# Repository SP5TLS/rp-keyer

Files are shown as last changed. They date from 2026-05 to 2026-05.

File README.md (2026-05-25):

# rp-keyer

RP2040 / RP2350 firmware that turns a Raspberry Pi Pico (or Pico 2) into a
self-contained CW (Morse) keyer with:

* iambic / straight / bug / ultimatic / single-paddle keyer engine from
  [`radio-utils-keyer`](https://crates.io/crates/radio-utils-keyer),
* on-device CW decoder from
  [`radio-utils-cw-decoder`](https://crates.io/crates/radio-utils-cw-decoder)
  feeding the OLED decoded-text row,
* USB MIDI + USB CDC SERIAL_STATE paddle interface (same wire contract
  as [cw-adapter](https://github.com/sp5tls/cw-adapter)),
* PWM-driven passive piezo buzzer for sidetone,
* 2N2222 NPN driver to key a real radio,
* SSD1306 128×64 OLED + 4-button menu for keyer settings.

## Pinout (default for both Pico / Pico 2)

Pins are grouped into two physical clusters on the Pico header so wiring
stays tidy whether you fly leads or build a PCB.

**Left edge — keyer hardware:**

| Function | Pin | GPIO | Notes |
|---|-----|---|---|
| Buzzer / GND | 13  | GND  | Shared with radio-key return |
| Buzzer | 14  | GP10 | PWM5A, drives passive piezo |
| Radio key out | 15  | GP11 | Drives 2N2222 base via 1 kΩ resistor |
| Paddle GND | 18  | GND  | TRS sleeve |
| Dit paddle | 19  | GP14 | TRS tip, active-low, internal pull-up |
| Dah paddle | 20  | GP15 | TRS ring, active-low, internal pull-up |

**Right edge — OLED + 4-button combo module (single 8-wire connector):**

| Module pin | Pico pin | GPIO  | Function |
|---|---|---|---|
| K1 | 21 | GP16  | Button UP (top of stack) |
| K2 | 22 | GP17  | Button DOWN |
| GND | 23 | GND | Module ground |
| K3 | 24 | GP18  | Button OK |
| K4 | 25 | GP19  | Button BACK (bottom of stack) |
| SDA | 26 | GP20  | I2C0 SDA |
| SCL | 27 | GP21  | I2C0 SCL |
| VCC | 36 | 3V3 | Single jumper to 3V3 OUT |

All eight module wires land on the same edge of the Pico — seven on the
contiguous right-side strip (pins 21–27) plus one jumper to 3V3.

## Radio key wiring

```
   GP11 ─── 1 kΩ ──── Base
                       │
                    2N2222 NPN
                       │
                    ┌──┴──┐
                    │     │
               Collector  Emitter
                    │     │
   radio key tip ───┘     └─── GND ─── radio key sleeve
   (or PTT)
```

Connections:

* **Base** ← GP11 through the 1 kΩ current-limiting resistor.
* **Collector** ← radio key tip (or PTT line). The radio's keying
  supply provides the pull-up; the 2N2222 sinks this line to ground
  when GP11 is high.
* **Emitter** → GND, shared with the radio key sleeve so the
  firmware and the radio agree on ground reference.

Drop a flyback diode across the collector–emitter (cathode to
collector) if your radio's key line is inductive.

The schematic uses a **2N3904** in this position; a **2N2222** is a
drop-in substitute — both are general-purpose NPN signal transistors
with more than enough current capacity for keying a typical radio.

## Schematics

A KiCad 8 project for the reference carrier board lives under
[`schematics/rp-keyer/`](schematics/rp-keyer/). It contains:

* `rp-keyer1.kicad_pro` — project file (open this in KiCad)
* `rp-keyer1.kicad_sch` — schematic
* `rp-keyer1.kicad_pcb` — PCB layout

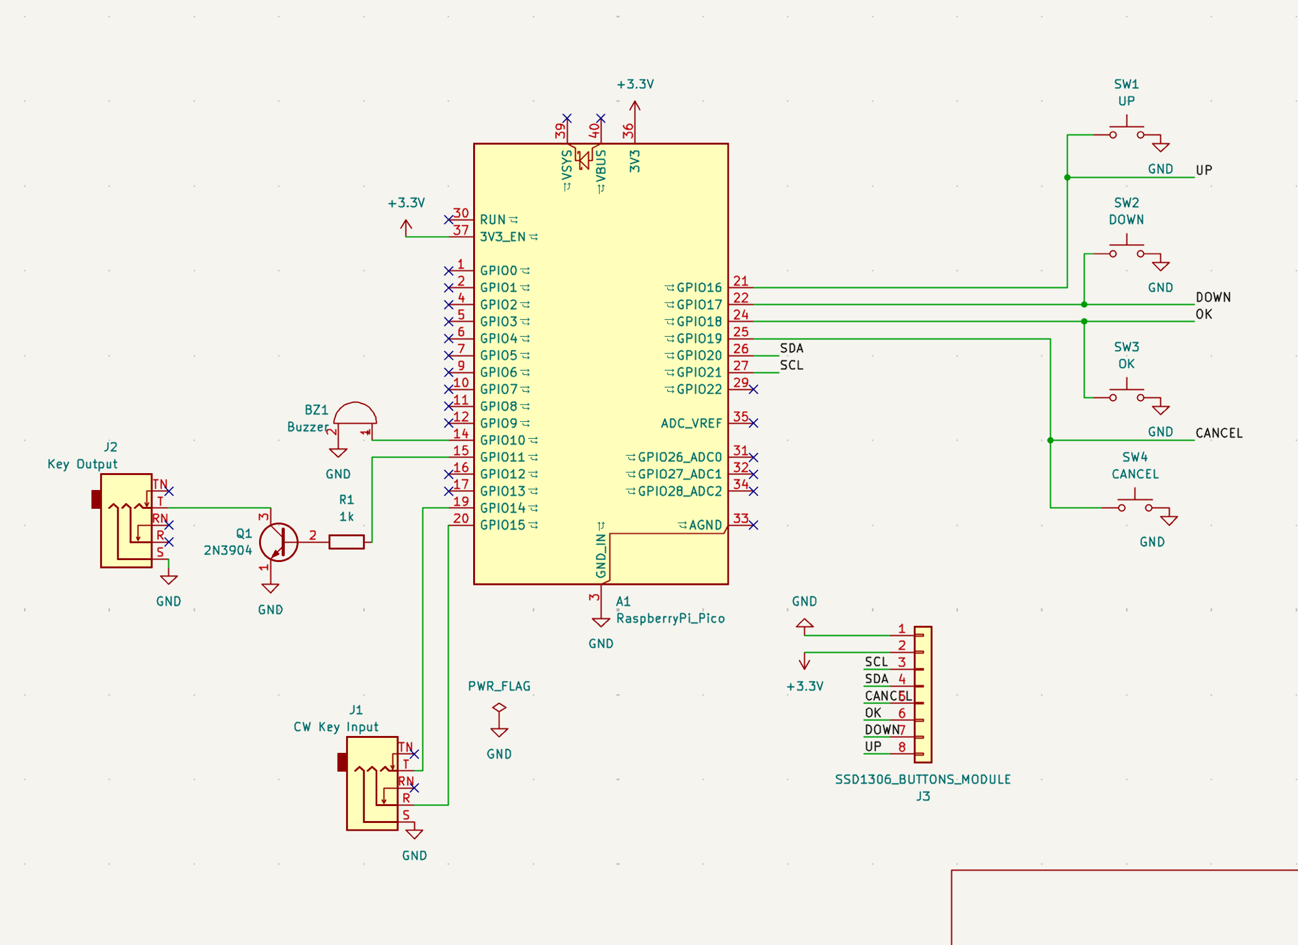
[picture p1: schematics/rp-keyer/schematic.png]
Schematic


The schematic captures the pinout above 1:1: paddle TRS jack `J1` on
GP14/GP15, radio-key TRS jack `J2` driven through Q1+R1 from GP11,
buzzer `BZ1` on GP10, and the 8-pin `SSD1306_BUTTONS_MODULE` connector
`J3` carrying SDA/SCL plus K1..K4 to GP16..GP21 with 3V3 + GND from the
top of the Pico.

## Pre-built firmware

Each tagged release publishes ready-to-flash `.uf2` files for both
boards on the [GitHub Releases page](https://github.com/sp5tls/rp-keyer/releases).
Hold BOOTSEL while plugging the board in, then drag the `.uf2` onto the
USB drive that appears.

## Building from source

```sh
# RP2040 (Pico)
cargo build --release \
  --target thumbv6m-none-eabi \
  --features rp2040,serial,midi \
  --bin rp2040

# RP2350 (Pico 2)
cargo build --release \
  --target thumbv8m.main-none-eabihf \
  --features rp2350,serial,midi \
  --bin rp2350
```

Generate a `.uf2` from the ELF:

```sh
cargo install elf2uf2-rs

elf2uf2-rs target/thumbv6m-none-eabi/release/rp2040 rp-keyer-rp2040.uf2
# For RP2350: elf2uf2-rs hardcodes the RP2040 family ID, so rewrite it
# afterwards or the Pico 2 BOOTSEL drive will reject the file.
elf2uf2-rs target/thumbv8m.main-none-eabihf/release/rp2350 rp-keyer-rp2350.uf2
python3 scripts/patch_uf2_family.py rp-keyer-rp2350.uf2
```

Flashing via `probe-rs`:

```sh
cargo run --release \
  --target thumbv6m-none-eabi \
  --features rp2040,serial,midi \
  --bin rp2040
```

## Menu

Boot screen shows the live mode / WPM / sidetone frequency.  `OK` enters
the settings list; `UP`/`DOWN` scroll, `OK` enters an item for editing,
`UP`/`DOWN` change the value, `OK` / `BACK` return.

Settable parameters:

* Mode (Straight / IambicA / IambicB / Bug / Ultimatic / SinglePaddle)
* WPM (5 – 60)
* Weight (25 – 75)
* Sidetone frequency (300 – 1200 Hz)
* Sidetone volume (0 – 100 %)
* Hang time (0 – 2000 ms)
* Keys reversed (Y / N)
* Iambic-B CMOS timing percentage (0 – 100)
* Farnsworth WPM (0 – 60, 0 = off)
* Keying compensation (0 – 50 ms)

## License

Dual-licensed under either of:

- [MIT license](LICENSE-MIT)
- [Apache License, Version 2.0](LICENSE-APACHE)

at your option.

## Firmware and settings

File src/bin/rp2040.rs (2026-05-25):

#![no_std]
#![no_main]

extern crate alloc;

#[cfg(feature = "serial")]
use rp_keyer::cdc_serial_state::{CdcWithSerialState, State as CdcState};
#[cfg(feature = "midi")]
use rp_keyer::midi_interrupt::MidiInterruptClass;

use rp_keyer::buttons::{ButtonInput, ButtonPanel};
use rp_keyer::buzzer::Buzzer;
use rp_keyer::radio_key::RadioKey;
use rp_keyer::shared::{ConfigDirtySignal, SharedConfig, SharedDecoder, UsbStateSignal};
use rp_keyer::storage::{self, AsyncFlash, FLASH_TOTAL_SIZE};
use rp_keyer::ui::{OledI2c, Ui};
use rp_keyer::usb_emit_task::UsbEmitApp;

use defmt::*;
use embassy_executor::{InterruptExecutor, Spawner};
use embassy_futures::select::{Either, select};
use embassy_rp::bind_interrupts;
use embassy_rp::flash::{Blocking, Flash};
use embassy_rp::gpio::{Input, Level, Output, Pull};
use embassy_rp::i2c::{self, Config as I2cConfig, I2c};
use embassy_rp::peripherals::{FLASH, I2C0, USB};
use embassy_rp::pwm::{Config as PwmConfig, Pwm};
use embassy_rp::usb::{Driver, InterruptHandler};
use embassy_time::{Duration, Timer};
use embassy_usb::Builder;
use embedded_alloc::LlffHeap as Heap;
use radio_utils_keyer::KeyerConfig;
use static_cell::StaticCell;

use {defmt_rtt as _, panic_probe as _};

defmt::timestamp!("{=u64:us}", embassy_time::Instant::now().as_micros());

#[defmt::panic_handler]
fn panic() -> ! {
    rp_keyer::safe_stop();
    cortex_m::asm::udf()
}

// ── Global allocator ─────────────────────────────────────────────────────
// The keyer engine uses Vec/VecDeque internally for text macros and the
// text_queue.  64 KiB is comfortable: macros peak at a few hundred
// elements; the transition log is a fixed-size heapless ring (see
// `MAX_RECORDED_TRANSITIONS` in radio_utils_keyer::engine) so it doesn't
// touch the heap at all; menu strings are heapless::String.
#[global_allocator]
static HEAP: Heap = Heap::empty();
const HEAP_SIZE: usize = 65_536;
static mut HEAP_MEM: [u8; HEAP_SIZE] = [0; HEAP_SIZE];

bind_interrupts!(struct Irqs {
    USBCTRL_IRQ => InterruptHandler<USB>;
    I2C0_IRQ => i2c::InterruptHandler<I2C0>;
});

// ── Shared state ─────────────────────────────────────────────────────────
static SHARED_CONFIG: StaticCell<SharedConfig> = StaticCell::new();
static KEY_INDICATOR: portable_atomic::AtomicBool = portable_atomic::AtomicBool::new(false);
/// `true` whenever the keyer engine is mid-element / has a held paddle
/// or pending PTT hang; updated each engine tick.  The persistence
/// task waits for this to fall to `false` before committing a save so
/// the ~50 ms flash-erase pause doesn't interrupt active keying.
static ENGINE_ACTIVE: portable_atomic::AtomicBool = portable_atomic::AtomicBool::new(false);
/// Handshake: the persistence task sets this to `true` after observing
/// `ENGINE_ACTIVE == false` and before calling the (~50 ms,
/// IRQs-disabled) flash erase.  The keyer task checks it at the top
/// of every iteration and parks if set — closes the race where the
/// engine could start keying between the persistence task's load and
/// the erase entry.  See `keyer_task::run`'s prologue and the
/// `config_persist_task` handshake comment.
static SAVE_LOCK: portable_atomic::AtomicBool = portable_atomic::AtomicBool::new(false);
/// Keyer → USB emit task channel.  Lossy by design — only the latest
/// snapshot matters; the consumer caches `prev_*` so a write failure
/// can't drop an edge.
static USB_SIGNAL: UsbStateSignal = embassy_sync::signal::Signal::new();
/// UI → persistence task — set on every config-mutating button press.
/// The persistence task debounces and waits for engine idle before
/// committing.
static CONFIG_DIRTY: ConfigDirtySignal = embassy_sync::signal::Signal::new();
/// Backing storage for the per-device USB serial number derived from
/// the flash unique-ID; lives in `.bss` so the descriptor table can
/// borrow it `'static`.
static SERIAL_BUF: StaticCell<[u8; 16]> = StaticCell::new();
/// CW decoder, shared between the keyer task (transition feeder) and
/// the UI task (poll + snapshot for the main-screen text row).  See
/// `shared::SharedDecoder` for the locking model.
static DECODER: SharedDecoder = embassy_sync::blocking_mutex::Mutex::new(core::cell::RefCell::new(
    radio_utils_cw_decoder::Decoder::new(),
));

// ── Tasks ────────────────────────────────────────────────────────────────
#[embassy_executor::task]
async fn usb_task(mut usb: embassy_usb::UsbDevice<'static, Driver<'static, USB>>) {
    usb.run().await;
}

#[embassy_executor::task]
async fn keyer_task(
    dit_pin: Input<'static>,
    dah_pin: Input<'static>,
    radio_key: RadioKey,
    buzzer: Buzzer,
    shared_config: &'static SharedConfig,
) {
    rp_keyer::keyer_task::run(
        dit_pin,
        dah_pin,
        radio_key,
        buzzer,
        shared_config,
        &KEY_INDICATOR,
        &USB_SIGNAL,
        &ENGINE_ACTIVE,
        &SAVE_LOCK,
        &DECODER,
    )
    .await;
}

#[embassy_executor::task]
async fn usb_emit_task(mut app: UsbEmitApp<'static, Driver<'static, USB>>) {
    app.run(&USB_SIGNAL).await;
}

#[embassy_executor::task]
async fn ui_task(
    i2c: OledI2c,
    mut buttons: ButtonPanel,
    shared_config: &'static SharedConfig,
) -> ! {
    let mut ui = Ui::new(i2c).await;

    let mut btn_buf = [rp_keyer::buttons::ButtonEvent::Up; 4];
    // Cached WPM + enabled flag for the decoder poll. Both refreshed
    // every render below; seeded from the persisted config so the very
    // first poll uses the right threshold and (when disabled) skips
    // the lock entirely.
    let (mut decoder_wpm, mut decoder_enabled) = {
        let cfg = shared_config.lock().await;
        (cfg.speed_wpm, cfg.decoder_enabled)
    };
    let mut decoded_buf = [0u8; 32];
    loop {
        ui.note_key_state(KEY_INDICATOR.load(portable_atomic::Ordering::Relaxed));

        let events = buttons.poll(&mut btn_buf);
        if !events.is_empty() {
            let mut guard = shared_config.lock().await;
            for &ev in events {
                ui.on_button(ev, &mut guard);
            }
            // Drop the guard before render so we don't hold it during
            // the (blocking) I2C flush.
            drop(guard);
            // Signal the persistence task on any edit — it debounces +
            // waits for idle before actually writing flash.
            if ui.take_config_changed() {
                CONFIG_DIRTY.signal(());
            }
        }

        // Poll + snapshot the decoder when it's enabled.  Closure runs
        // under a critical section — keep it strictly to the decoder
        // calls and a small memcpy.  Both keyer task (writer) and UI
        // task (reader) take this lock; lock duration ≪ 1 µs so the
        // keyer task on SWI_IRQ_1 is never delayed appreciably.
        if decoder_enabled {
            let now_us = embassy_time::Instant::now().as_micros();
            let n = DECODER.lock(|d| {
                let mut d = d.borrow_mut();
                d.poll(now_us, decoder_wpm);
                d.snapshot(&mut decoded_buf)
            });
            ui.note_decoded(&decoded_buf[..n]);
        }

        // Only snapshot the config when there's actually something to
        // draw — avoids the [String; 8] clone + critical section every
        // 25 ms when nothing on screen changed.
        if ui.is_dirty() {
            let cfg_snap: KeyerConfig = shared_config.lock().await.clone();
            decoder_wpm = cfg_snap.speed_wpm;
            decoder_enabled = cfg_snap.decoder_enabled;
            ui.render(&cfg_snap);
        }

        Timer::after(Duration::from_millis(25)).await;
    }
}

/// Debounce-and-commit task for settings persistence.
///
/// State machine: wait → debounce → acquire-save-window → save.
///
/// * **wait** — block on `CONFIG_DIRTY` until the UI signals an edit.
/// * **debounce** — each further edit within 3 s extends the window.
///   Avoids 8 flash writes when the user scrolls a slider up by 8.
/// * **acquire-save-window** — flash erase disables interrupts for
///   ~50 ms, so we need the keyer engine to be quiescent for the
///   duration.  Two-step handshake:
///
///     1. wait for `ENGINE_ACTIVE == false`,
///     2. set `SAVE_LOCK = true` and wait one millisecond (4 keyer
///        ticks at the 250 µs cadence) for the keyer to observe it,
///     3. recheck `ENGINE_ACTIVE`.  If it raced (paddle press landed
///        in step 1's gap before the keyer parked), release the lock
///        and retry.  Otherwise the keyer is parked at its prologue
///        and won't drive the key line until we clear `SAVE_LOCK`.
///
/// * **save** — snapshot the shared config and append to the ring.
///   IRQs go off for ~50 ms during the erase; the keyer task is
///   already parked, so this is safe.  Clear `SAVE_LOCK` when done.
#[embassy_executor::task]
async fn config_persist_task(mut flash: AsyncFlash, shared_config: &'static SharedConfig) {
    const DEBOUNCE: Duration = Duration::from_secs(3);
    const IDLE_RECHECK: Duration = Duration::from_millis(250);
    /// Long enough for the keyer task (250 µs cadence) to observe
    /// SAVE_LOCK and have updated ENGINE_ACTIVE one more time so the
    /// recheck reflects post-park reality.
    const PARK_OBSERVE: Duration = Duration::from_millis(1);

    loop {
        // Wait for the first dirty signal of this batch.
        CONFIG_DIRTY.wait().await;

        // Debounce: each new dirty signal restarts the 3-second window.
        // The loop exits as soon as `Timer::after(DEBOUNCE)` wins, i.e.
        // the user has been quiet for the full window.
        while let Either::First(_) = select(CONFIG_DIRTY.wait(), Timer::after(DEBOUNCE)).await {}

        // Acquire-save-window handshake — see task docstring.
        loop {
            while ENGINE_ACTIVE.load(portable_atomic::Ordering::Relaxed) {
                Timer::after(IDLE_RECHECK).await;
            }
            SAVE_LOCK.store(true, portable_atomic::Ordering::Relaxed);
            Timer::after(PARK_OBSERVE).await;
            if !ENGINE_ACTIVE.load(portable_atomic::Ordering::Relaxed) {
                break;
            }
            // Raced — a paddle press landed between the engine-active
            // check and the lock store.  Release and retry.
            SAVE_LOCK.store(false, portable_atomic::Ordering::Relaxed);
            Timer::after(IDLE_RECHECK).await;
        }

        let cfg = shared_config.lock().await.clone();
        match storage::save_config(&mut flash, &cfg).await {
            Ok(()) => info!("settings saved"),
            Err(()) => warn!("settings save failed"),
        }
        SAVE_LOCK.store(false, portable_atomic::Ordering::Relaxed);
    }
}

// ── Interrupt executor for the keyer task ────────────────────────────────
static EXECUTOR_HIGH: InterruptExecutor = InterruptExecutor::new();

#[unsafe(no_mangle)]
#[allow(non_snake_case)]
unsafe extern "C" fn SWI_IRQ_1() {
    unsafe { EXECUTOR_HIGH.on_interrupt() }
}

/// Read the RP2040 flash unique ID and format it as 16 hex chars into
/// `buf`.  Falls back to a fixed string if the flash read errors so
/// the USB enumeration still has *some* serial.
fn read_flash_serial_into(
    flash: &mut Flash<'static, FLASH, Blocking, { FLASH_TOTAL_SIZE }>,
    buf: &'static mut [u8; 16],
) -> &'static str {
    let mut uid = [0u8; 8];
    if flash.blocking_unique_id(&mut uid).is_ok() {
        const HEX: &[u8; 16] = b"0123456789abcdef";
        for (i, byte) in uid.iter().enumerate() {
            buf[2 * i] = HEX[(byte >> 4) as usize];
            buf[2 * i + 1] = HEX[(byte & 0x0F) as usize];
        }
    } else {
        // Deterministic 16-byte fallback so two enumeration attempts
        // don't churn the OS's USB device cache.
        buf.copy_from_slice(b"rpk-rp2040-0000\0");
    }
    // Safety: every byte above is ASCII (hex digits or the printable
    // fallback string), so it's valid UTF-8.
    unsafe { core::str::from_utf8_unchecked(buf.as_slice()) }
}

// ── Main ─────────────────────────────────────────────────────────────────
#[embassy_executor::main]
async fn main(spawner: Spawner) {
    // Initialise the heap before anything that touches the keyer crate
    // (KeyerEngine::new allocates a Vec).
    unsafe {
        HEAP.init(core::ptr::addr_of_mut!(HEAP_MEM) as usize, HEAP_SIZE);
    }

    let p = embassy_rp::init(Default::default());

    info!("radio-utils-firmware booting (RP2040)");

    // ── Flash driver: unique-ID read for USB serial + settings ring ──
    let mut flash: Flash<'static, FLASH, Blocking, { FLASH_TOTAL_SIZE }> =
        Flash::new_blocking(p.FLASH);
    let serial_number = read_flash_serial_into(&mut flash, SERIAL_BUF.init([0u8; 16]));
    let mut async_flash = AsyncFlash::new(flash);

    // ── Try to load saved settings; fall back to defaults ────────────
    let initial_cfg: KeyerConfig = match storage::load_config(&mut async_flash).await {
        Some(cfg) => {
            info!("settings restored from flash");
            cfg
        }
        None => {
            info!("no saved settings — using defaults");
            KeyerConfig::default()
        }
    };

    // ── Shared keyer config ──────────────────────────────────────────
    let shared_config: &'static SharedConfig =
        SHARED_CONFIG.init(embassy_sync::mutex::Mutex::new(initial_cfg));

    // ── USB ──────────────────────────────────────────────────────────
    let driver = Driver::new(p.USB, Irqs);
    let mut usb_config = embassy_usb::Config::new(0x16c0, 0x27dc);
    usb_config.manufacturer = Some("radio-utils");
    usb_config.product = Some("CW Keyer + Interface");
    usb_config.serial_number = Some(serial_number);
    usb_config.max_power = 100;
    usb_config.max_packet_size_0 = 64;

    static CONFIG_DESCRIPTOR: StaticCell<[u8; 512]> = StaticCell::new();
    static BOS_DESCRIPTOR: StaticCell<[u8; 256]> = StaticCell::new();
    static CONTROL_BUF: StaticCell<[u8; 64]> = StaticCell::new();

    let mut builder = Builder::new(
        driver,
        usb_config,
        CONFIG_DESCRIPTOR.init([0; 512]),
        BOS_DESCRIPTOR.init([0; 256]),
        &mut [],
        CONTROL_BUF.init([0; 64]),
    );

    #[cfg(feature = "serial")]
    let serial = {
        static CDC_STATE: StaticCell<CdcState> = StaticCell::new();
        Some(CdcWithSerialState::new(
            &mut builder,
            CDC_STATE.init(CdcState::new()),
            64,
        ))
    };

    #[cfg(feature = "midi")]
    let midi = Some(MidiInterruptClass::new(&mut builder, 1, 0, 64, 1));

    let usb = builder.build();
    spawner.spawn(usb_task(usb).unwrap());

    // Pinout is grouped into two physical clusters on the Pico header so
    // both flying-lead wiring and a future PCB stay tidy. See README.
    //
    // Left edge — keyer hardware:
    //   pin 14 GP10 buzzer (PWM5A)
    //   pin 15 GP11 radio key out (2N2222 base)
    //   pin 19 GP14 Dit paddle  (TRS tip,   GND on pin 18)
    //   pin 20 GP15 Dah paddle  (TRS ring,  GND on pin 18)
    //
    // Right edge — OLED + 4-button combo module (8-wire connector):
    //   pin 21 GP16 K1 = UP
    //   pin 22 GP17 K2 = DOWN
    //   pin 23 GND  module GND
    //   pin 24 GP18 K3 = OK
    //   pin 25 GP19 K4 = BACK
    //   pin 26 GP20 SDA (I2C0)
    //   pin 27 GP21 SCL (I2C0)
    //   pin 36 3V3  module VCC

    let dit_pin = Input::new(p.PIN_14, Pull::Up);
    let dah_pin = Input::new(p.PIN_15, Pull::Up);

    let radio_key = RadioKey::new(Output::new(p.PIN_11, Level::Low));

    let buzzer = {
        let pwm_cfg = PwmConfig::default();
        let pwm = Pwm::new_output_a(p.PWM_SLICE5, p.PIN_10, pwm_cfg);
        Buzzer::new(pwm)
    };

    let oled_i2c: OledI2c = {
        let mut cfg = I2cConfig::default();
        cfg.frequency = 400_000;
        I2c::new_blocking(p.I2C0, p.PIN_21, p.PIN_20, cfg)
    };

    let buttons = ButtonPanel {
        up: ButtonInput::new(Input::new(p.PIN_16, Pull::Up)),
        down: ButtonInput::new(Input::new(p.PIN_17, Pull::Up)),
        ok: ButtonInput::new(Input::new(p.PIN_18, Pull::Up)),
        back: ButtonInput::new(Input::new(p.PIN_19, Pull::Up)),
    };

    // ── Spawn UI + USB emit + persistence on the thread executor ─────
    spawner.spawn(ui_task(oled_i2c, buttons, shared_config).unwrap());
    spawner.spawn(config_persist_task(async_flash, shared_config).unwrap());

    let usb_emit_app = UsbEmitApp {
        #[cfg(feature = "serial")]
        serial,
        #[cfg(feature = "midi")]
        midi,
        #[cfg(not(any(feature = "serial", feature = "midi")))]
        _marker: core::marker::PhantomData,
    };
    spawner.spawn(usb_emit_task(usb_emit_app).unwrap());

    // ── Interrupt priorities ─────────────────────────────────────────
    // All NVIC priorities default to P0; the InterruptExecutor running
    // on SWI_IRQ_1 then can't preempt USBCTRL_IRQ / I2C0_IRQ even
    // though it's the highest-latency-sensitive code on the chip.
    // Lower USB + I2C to P3 (lowest) and keep SWI at P0 so the keyer
    // task can actually meet its 250 µs cadence.
    use embassy_rp::interrupt::{InterruptExt, Priority};
    embassy_rp::interrupt::USBCTRL_IRQ.set_priority(Priority::P3);
    embassy_rp::interrupt::I2C0_IRQ.set_priority(Priority::P3);
    embassy_rp::interrupt::SWI_IRQ_1.set_priority(Priority::P0);

    // ── Spawn keyer task on the elevated-priority interrupt executor ─
    let hi_spawner = EXECUTOR_HIGH.start(embassy_rp::pac::Interrupt::SWI_IRQ_1);

    hi_spawner.spawn(keyer_task(dit_pin, dah_pin, radio_key, buzzer, shared_config).unwrap());

    loop {
        embassy_time::Timer::after(embassy_time::Duration::from_secs(3600)).await;
    }
}

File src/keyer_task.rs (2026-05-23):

//! High-priority keyer loop.
//!
//! Runs on the interrupt executor at a 250 µs cadence.  Paddle reads,
//! debouncing, USB-snapshot signalling and engine ticks all happen
//! every 250 µs — the engine is constructed via `new_with_tick(_, 250)`
//! so each `tick()` advances `elapsed_us` by 250 µs and the
//! schedule-phase residual handling is matched to the same quantum.
//!
//! At the previous 1 ms engine quantum, 28 WPM produced a repeating
//! 43-43-43-43-43-43-42 ms dit pattern because `1200 / 28 = 42.857 ms`
//! doesn't fall on a 1 ms grid; the residual built up and the engine
//! emitted a short dit every 7 elements.  At 250 µs that swing shrinks
//! to a single tick (250 µs) — below the audibility threshold and
//! within the bound the schedule-phase carry was designed for.
//!
//! USB I/O does **not** run in this task.  A `Signal<UsbSnapshot>`
//! carries the latest paddle / engine-key state to a separate
//! low-priority `usb_emit_task`, so a USB endpoint poll (≤ 1 ms per
//! interrupt-IN transfer) can never stretch the keyer's 250 µs cadence
//! and warp the engine's perception of wall-clock time.
//!
//! Paddle debounce: `debounce_threshold × 250 µs` — currently ~2 ms
//! (8 samples) to stay above real-world paddle contact bounce.  Tighter
//! thresholds let release-bounce sneak through and the iambic memory
//! turns one tap into two elements (see `dit_debounce` in `run`).

use embassy_rp::gpio::Input;
use embassy_time::{Duration, Instant, Ticker};
use radio_utils_keyer::{KeyerConfig, KeyerEngine, KeyerOutput, UsbEmitStyle};

use crate::buzzer::Buzzer;
use crate::paddle::Debouncer;
use crate::radio_key::RadioKey;
use crate::shared::{SharedConfig, SharedDecoder, UsbSnapshot, UsbStateSignal};

/// Keyer poll + engine tick interval.  Drives both the paddle debounce
/// cadence and the engine's time advance — both updated at this rate.
const POLL_INTERVAL_US: u32 = 250;

/// Config refresh throttle, expressed in ticks.  ~50 ms between
/// re-locks of the shared mutex (200 × 250 µs).
const CONFIG_REFRESH_TICKS: u32 = (50 * 1000) / POLL_INTERVAL_US;

/// Feed a key transition to the CW decoder. Held under the decoder's
/// critical-section lock for just the duration of `on_transition` —
/// O(1) work, well under a microsecond, so it never extends the
/// keyer task's 250 µs cadence.
///
/// Called twice in close succession for each key-down: once from
/// `PttRequest(true)` (one engine tick before the actual element
/// edge) and once from the following `KeyDown`. That matches the
/// on-air key line — `PttRequest(true)` already drives the GPIO low —
/// so the decoder is correctly observing the keyed signal. The second
/// call lands with `state == Down`, so `process_gap` short-circuits;
/// only `last_transition_us` advances by the ~250 µs between the two
/// events, which biases the next gap by the same amount (≈ 0.4% of a
/// dit at 18 WPM — well below decode-threshold sensitivity).
#[inline]
fn feed_decoder(decoder: &'static SharedDecoder, key_down: bool, wpm: u8) {
    let now_us = Instant::now().as_micros();
    decoder.lock(|d| d.borrow_mut().on_transition(now_us, key_down, wpm));
}

/// Main keyer loop.  Never returns.
#[allow(clippy::too_many_arguments)] // each parameter is a distinct piece of wiring with no natural grouping
pub async fn run(
    dit_pin: Input<'static>,
    dah_pin: Input<'static>,
    mut radio_key: RadioKey,
    mut buzzer: Buzzer,
    shared_config: &'static SharedConfig,
    key_indicator: &'static portable_atomic::AtomicBool,
    usb_signal: &'static UsbStateSignal,
    engine_active: &'static portable_atomic::AtomicBool,
    save_lock: &'static portable_atomic::AtomicBool,
    decoder: &'static SharedDecoder,
) -> ! {
    // Seed the engine with the current config snapshot.
    let mut keys_reversed: bool;
    let mut emit_style: UsbEmitStyle;
    let mut wpm: u8;
    let mut decoder_enabled: bool;
    let initial_cfg: KeyerConfig = {
        let guard = shared_config.lock().await;
        keys_reversed = guard.keys_reversed;
        emit_style = guard.usb_emit_style;
        wpm = guard.speed_wpm;
        decoder_enabled = guard.decoder_enabled;
        guard.clone()
    };
    buzzer.update_settings(initial_cfg.sidetone_freq, initial_cfg.sidetone_volume);
    let mut engine = KeyerEngine::new_with_tick(initial_cfg, POLL_INTERVAL_US);

    // 8 consecutive samples ≈ 2 ms debounce.  Mechanical paddles
    // can bounce for 1–3 ms on release; anything shorter lets the
    // bounce-back-to-pressed rising edge through and the iambic
    // engine latches it as a fresh dit_memory during the next
    // inter-element gap, producing a phantom second dit (the
    // classic "double-dit on one tap" failure mode at 18 WPM).
    // 2 ms is far below the shortest intentional dit at 60 WPM
    // (≈ 20 ms) so it costs nothing in element fidelity.
    let mut dit_debounce = Debouncer::new(false, 8);
    let mut dah_debounce = Debouncer::new(false, 8);

    // Live engine key state — flipped by KeyDown/KeyUp/PttRequest(true)
    // and shipped to usb_emit_task via the Signal so the host sees
    // engine-keyed transitions even in Keyed emit mode.
    let mut live_key: bool = false;
    let mut last_signaled: Option<UsbSnapshot> = None;

    // Counts engine ticks for the config-refresh throttle.  Resets to
    // 0 on each fire rather than wrapping a u32 — avoids a spurious
    // refresh at u32::MAX → 0 (the previous `is_multiple_of` check
    // matched 0 too, so the wrap moment triggered an extra refresh).
    let mut refresh_counter: u32 = 0;

    // Fixed-interval ticker rather than `Timer::after(POLL_INTERVAL_US)`
    // — the latter measures from end-of-body, so any per-iteration jitter
    // (engine state branch, periodic config clone, etc.) accumulated as
    // wall-clock drift while the engine's `elapsed_us` advanced by a
    // fixed quantum per tick.  `Ticker` fires on absolute interval
    // boundaries so engine ticks track wall clock.
    let mut ticker = Ticker::every(Duration::from_micros(POLL_INTERVAL_US as u64));
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

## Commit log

2026-05-23 Initial commit: rp-keyer firmware for RP2040 / RP2350
    Stand-alone firmware crate extracted from the radio-utils workspace
    (was crates/radio-utils-firmware there) so it can ship as its own repo
    with its own release cadence and UF2 build pipeline.
    Library dependencies (radio-utils-keyer, radio-utils-cw-decoder) are
    pulled from crates.io at 0.1.1 instead of workspace path deps, so the
    firmware is fully self-contained.
    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
2026-05-23 CI: publish rolling `latest` UF2 release on master pushes
    - Trigger release.yml on push to master in addition to v* tags; tag
    resolver picks `latest` for branch pushes, the existing tag name
    otherwise.
    - Before re-publishing `latest`, delete the prior release + tag so the
    tag relocates to the new commit (softprops/action-gh-release won't
    move an existing tag).
    - Mark `latest` builds as prereleases, name them "Latest master build",
    and record the source SHA in the release body.
    - Add a `release-${ref}` concurrency group so rapid master pushes don't
    race on the same tag.
    Also drop the vail-adapter mention from the README and apply the
    rustfmt-collapsed single-line `use rp_keyer::s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
    [rp2040.rs, rp2350.rs]
2026-05-23 CI: force-reinstall cargo binstall payloads to survive partial cache hits
    rust-cache restores binstall's 'already installed' metadata without
    necessarily restoring the matching ~/.cargo/bin/ binaries, so on a cache
    hit binstall short-circuits and rust-objcopy is missing when the Package
    artifacts step runs. Pass --force so the binaries are always
    materialized.
2026-05-23 CI: opt JS actions into Node.js 24 to silence Node 20 deprecation
    upload-artifact@v4, download-artifact@v4, softprops/action-gh-release@v2
    and other JS actions still bundle Node 20 and emit a deprecation warning
    on every run. The warning text recommends setting
    FORCE_JAVASCRIPT_ACTIONS_TO_NODE24=true to opt those actions into Node 24
    ahead of the June 2026 default switch.
2026-05-25 Rework pinout for single-edge wiring
    Group all keyer hardware on the left edge of the Pico header and route
    the OLED + 4-button combo module to a single contiguous run on the
    right edge, so a stock 8-wire connector reaches the whole module.
    Pin assignments:
    * Buzzer GP10 (PWM5A, was GP19 / PWM1B)
    * Radio key out GP11 (was GP18)
    * Dit / Dah GP14 / GP15 (unchanged)
    * Buttons GP16..GP19 (UP, DOWN, OK, BACK; were GP10..GP13)
    * OLED GP20 SDA, GP21 SCL (unchanged)
    Update RADIO_KEY_PIN and BUZZER_PWM_SLICE so safe_stop() still
    disarms the radio key and silences the buzzer on panic, and switch
    Buzzer to drive PWM channel A (compare_a) to match the new
    new_output_a wirin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
    [buzzer.rs, lib.rs, rp2040.rs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]
2026-05-25 Add KiCad schematic and PCB for reference carrier board
    KiCad 8 project under schematics/rp-keyer/ captures the firmware
    pinout 1:1 — paddle TRS jack on GP14/GP15, radio-key TRS jack driven
    through a 2N3904 + 1 kΩ from GP11, buzzer on GP10, and the 8-pin
    SSD1306_BUTTONS_MODULE connector carrying SDA/SCL + K1..K4 to
    GP16..GP21.
    Also ignore KiCad per-user artifacts (*.kicad_prl, *-backups/,
    *.kicad_bak, fp-info-cache) and the VS Code Local History extension's
    .history/ directory.
    [rp-keyer1.kicad_pcb, rp-keyer1.kicad_sch]
